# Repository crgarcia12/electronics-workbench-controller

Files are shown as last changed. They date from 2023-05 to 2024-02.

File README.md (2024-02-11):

# My Workbench!
This project builds a shelf for electronic devices that can be controlled remotely or via a control pannel in the shelf

The board has:
- Three shift registers with ULN controllers with 24 high current output
- I2C IO expander with sixteen inputs

## PCB
PCB
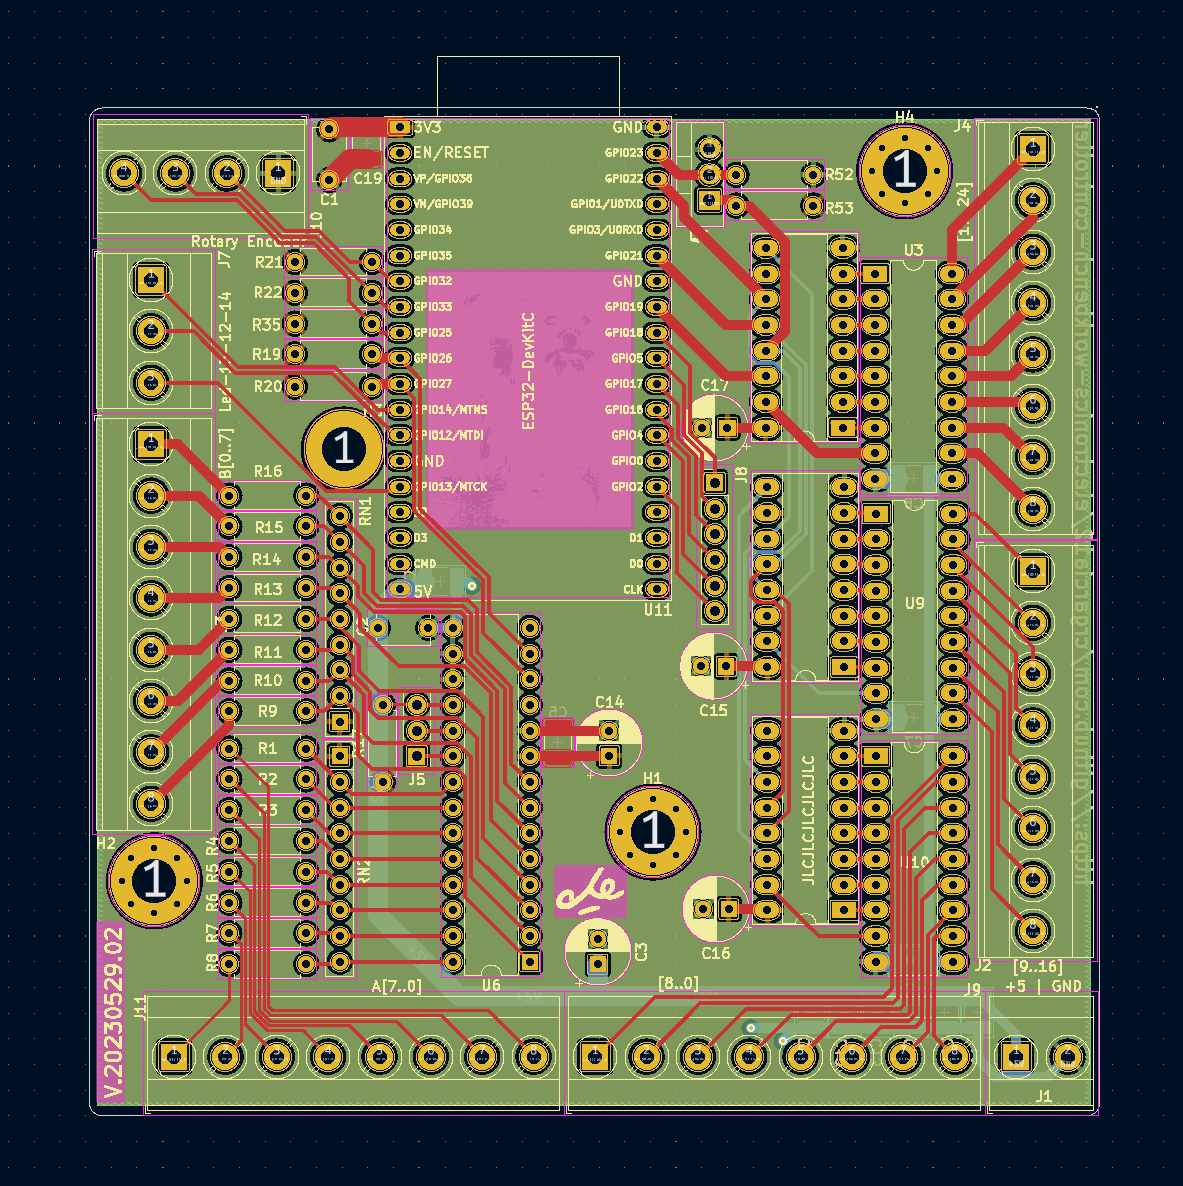
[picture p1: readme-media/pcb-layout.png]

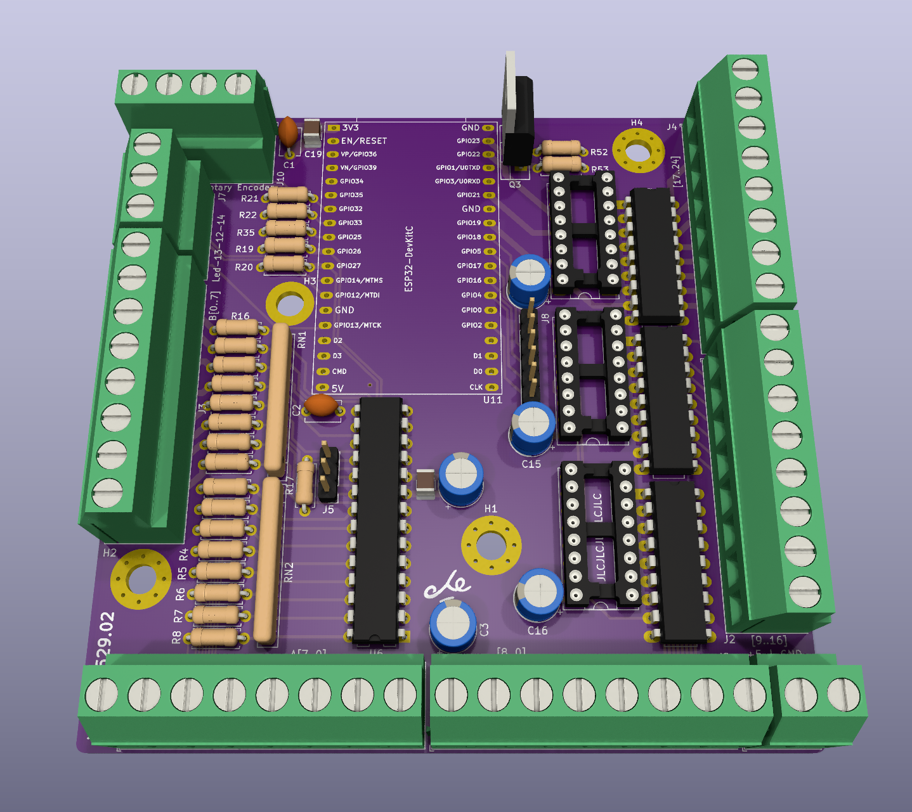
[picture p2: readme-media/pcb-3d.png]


## The Shelf in progress
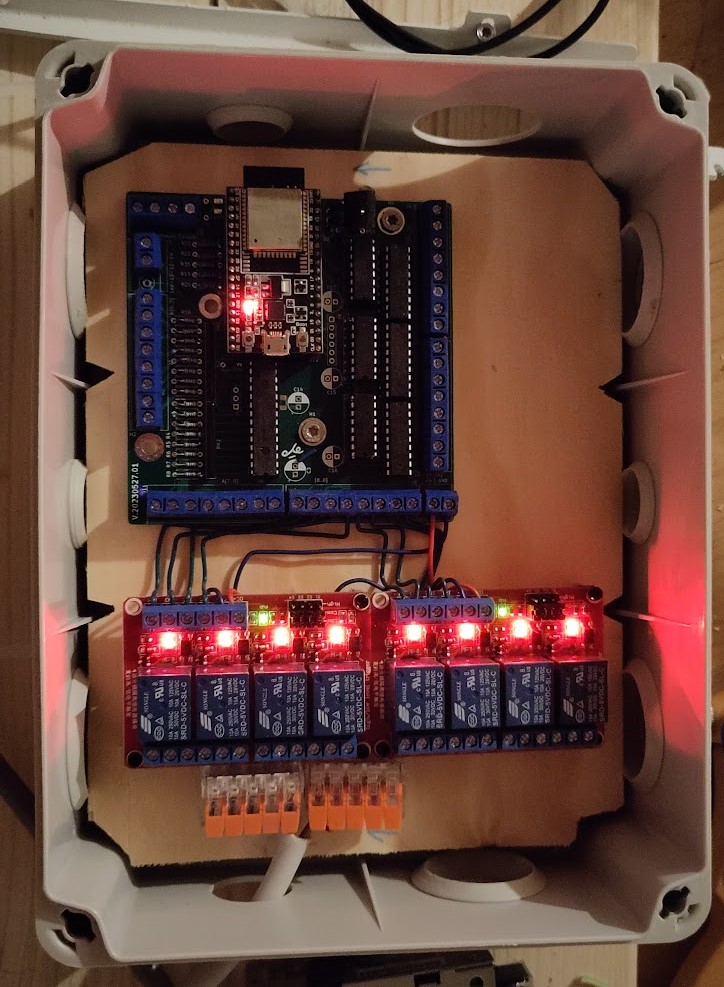
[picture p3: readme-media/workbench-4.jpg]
Workbench

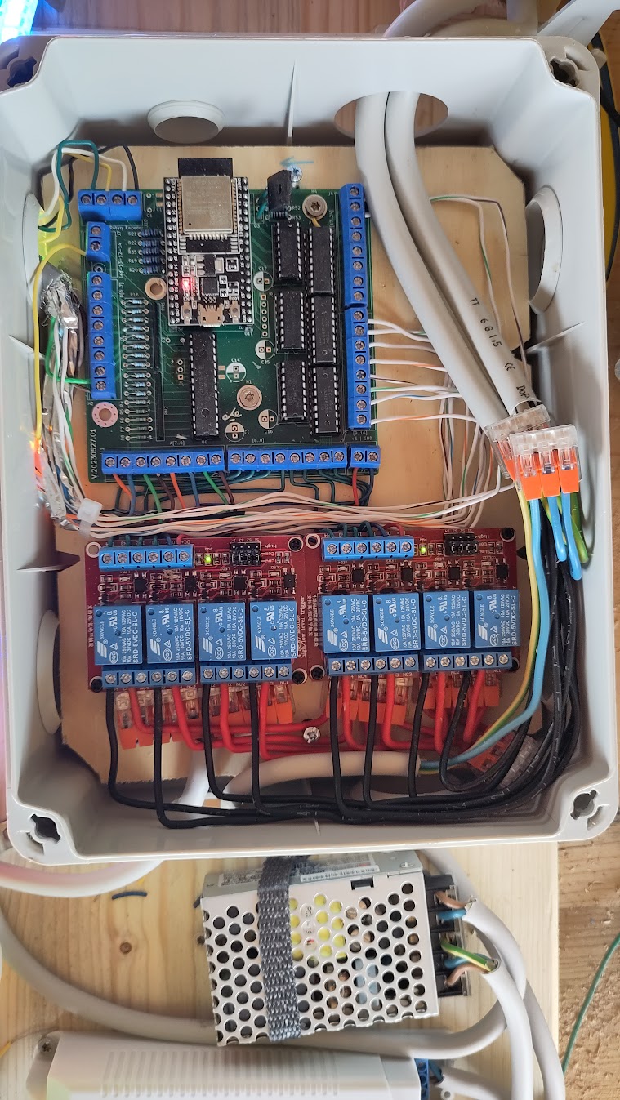
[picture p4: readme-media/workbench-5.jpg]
Workbench

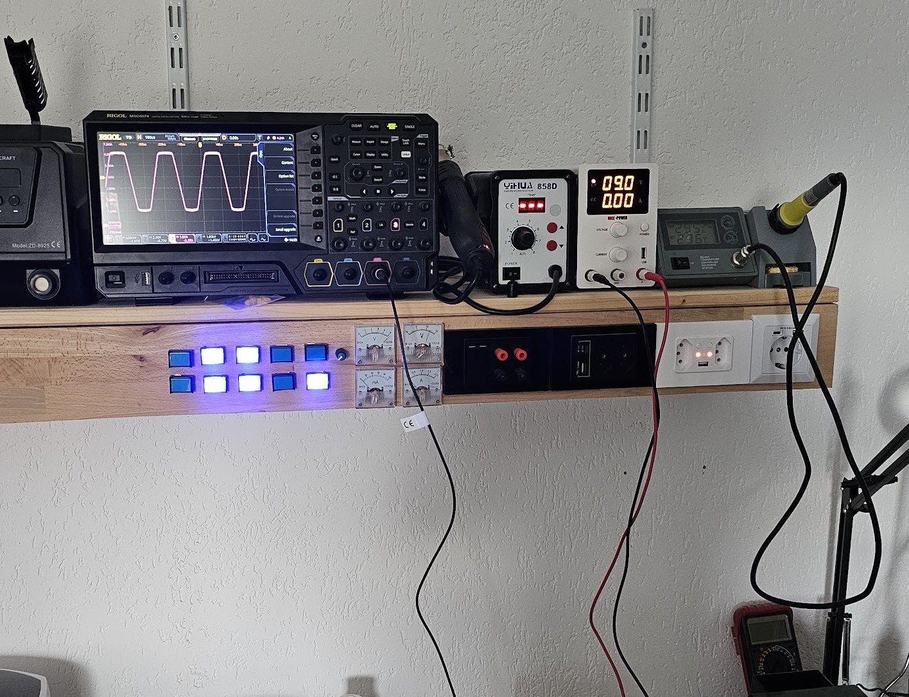
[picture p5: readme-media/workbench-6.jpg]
Workbench

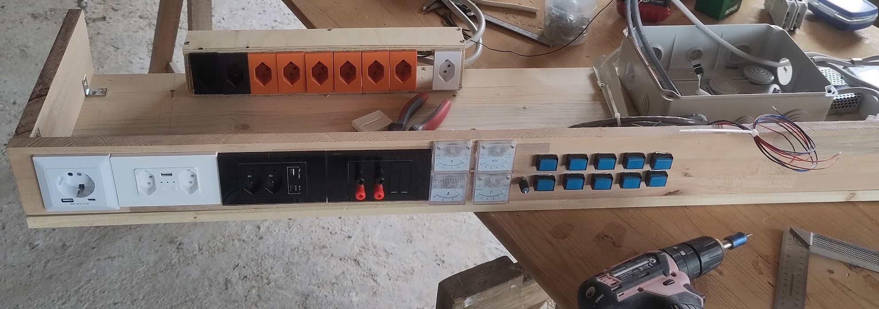
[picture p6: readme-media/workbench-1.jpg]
Workbench

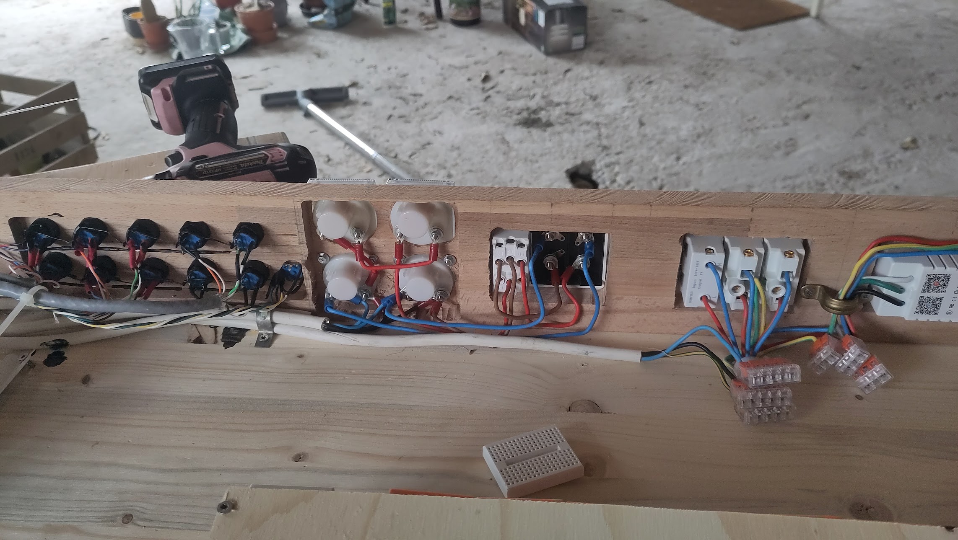
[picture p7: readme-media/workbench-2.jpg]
Workbench

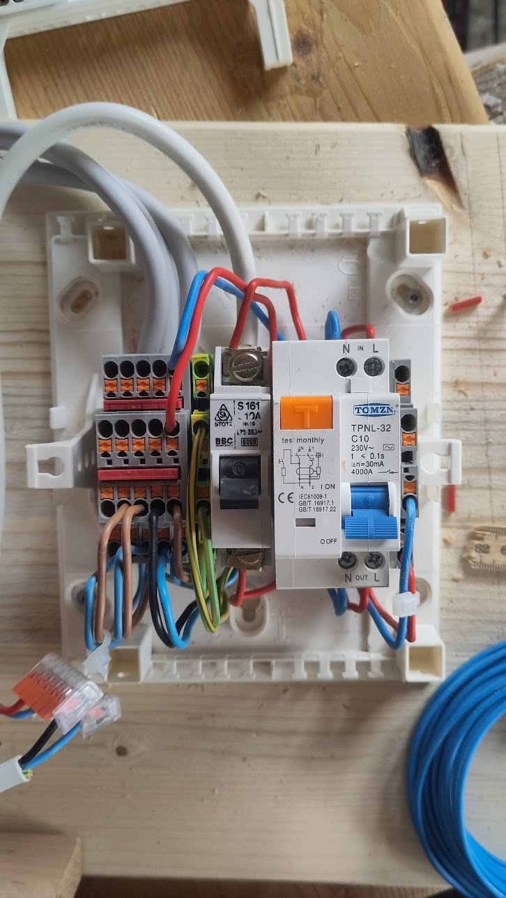
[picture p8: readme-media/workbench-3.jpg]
Workbench

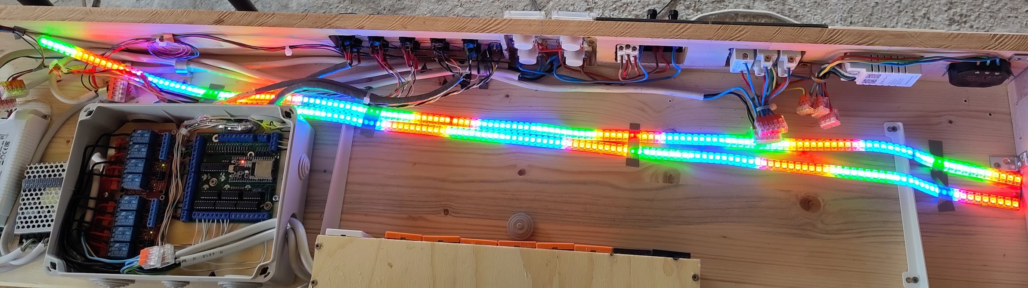
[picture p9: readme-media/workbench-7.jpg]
Workbench


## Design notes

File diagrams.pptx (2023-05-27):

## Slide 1

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
Shalter

TB

TB

TB

5V PS

12V PS

Relay Board 2

Esp32 Board

Relay Board 1

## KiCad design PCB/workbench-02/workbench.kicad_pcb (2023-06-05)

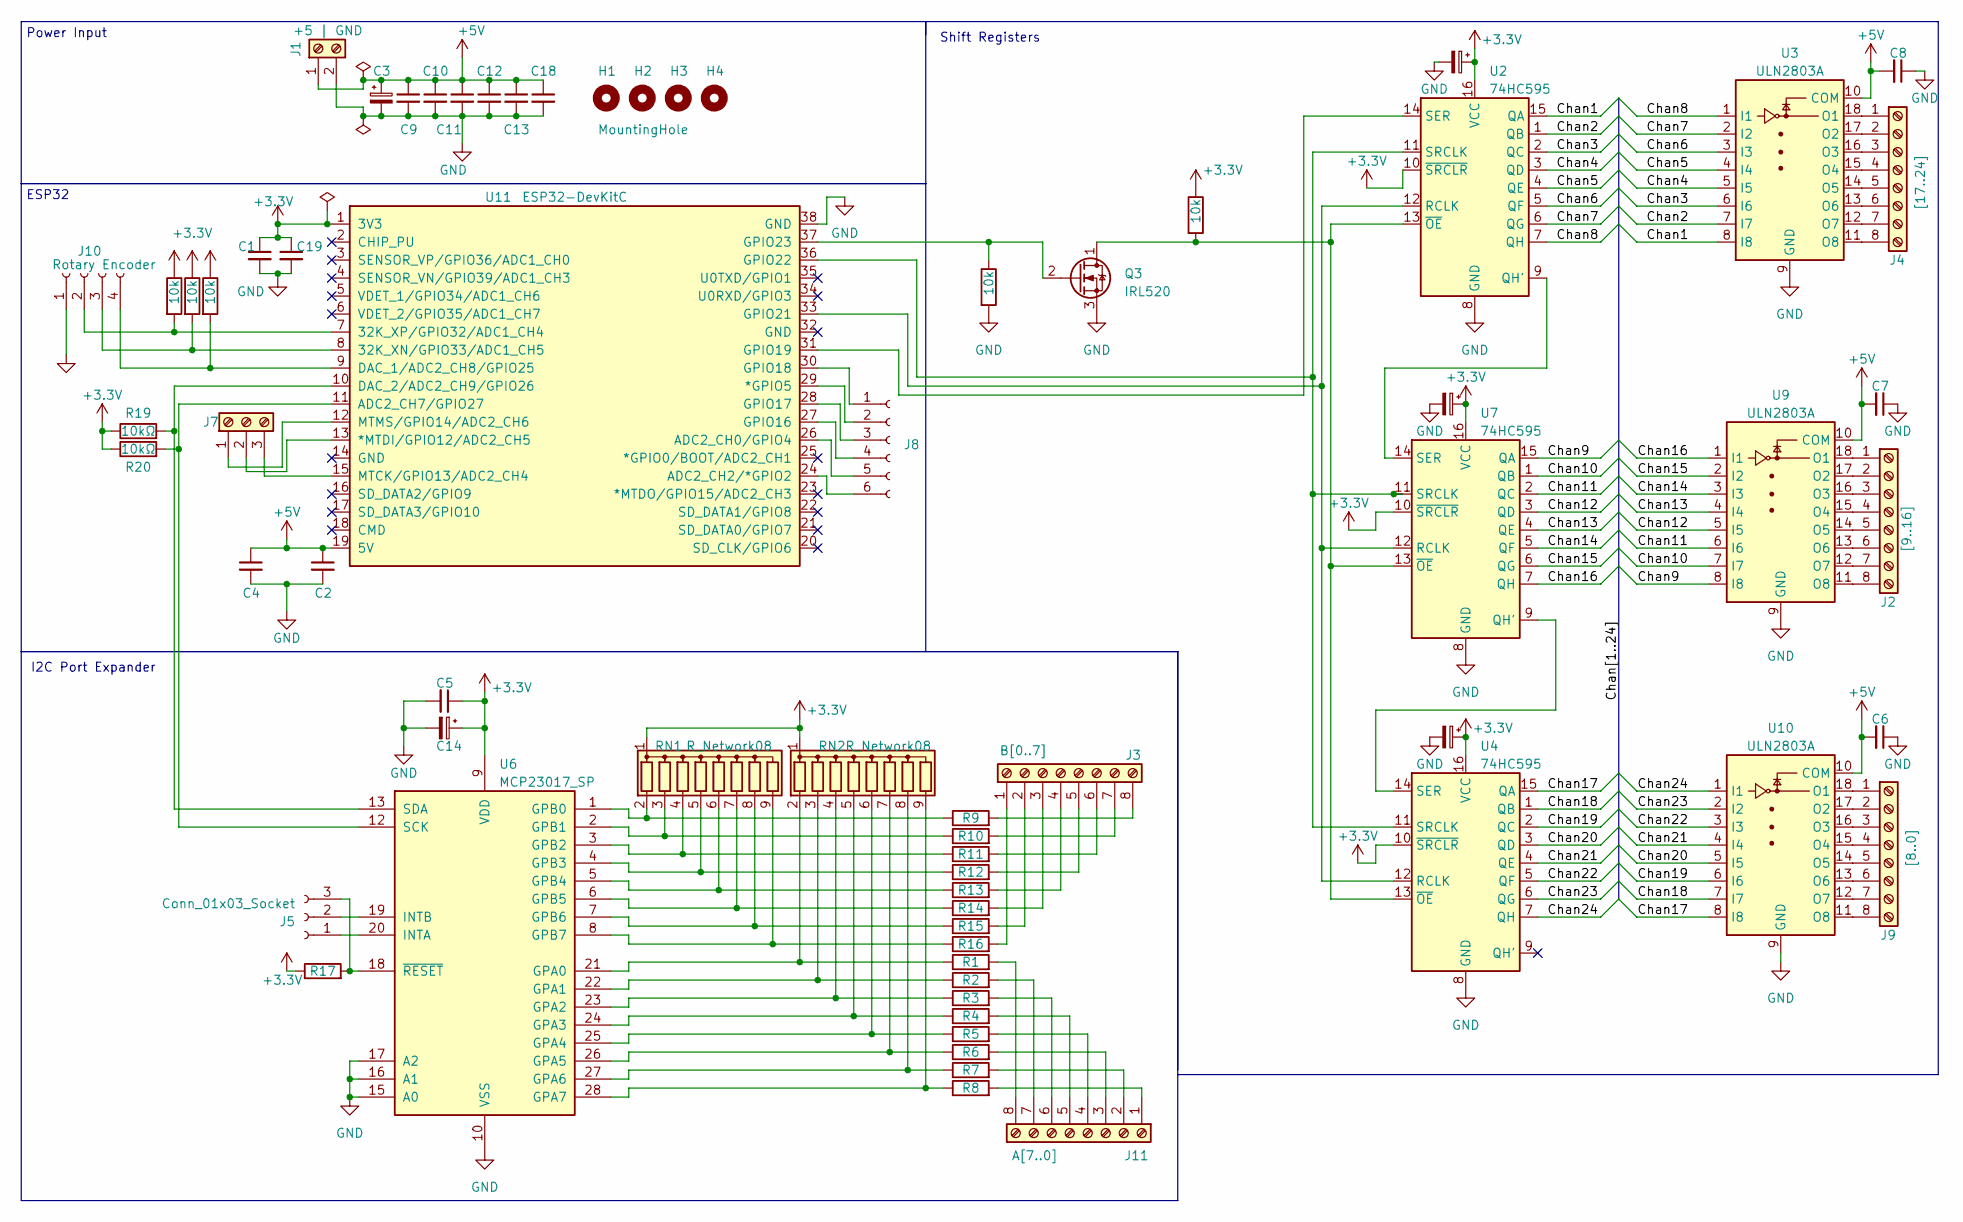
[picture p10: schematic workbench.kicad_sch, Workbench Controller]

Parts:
C1, C2: C; C_Disc_D5.1mm_W3.2mm_P5.00mm
C3, C14, C15, C16, C17: 10uF; CP_Radial_D6.3mm_P2.50mm
C4, C5, C6, C7, C8, C9, C10, C11, C12, C13, C18, C19: C; C_1210_3225Metric_Pad1.33x2.70mm_HandSolder
H1, H2, H4: MountingHole; MountingHole_4.3mm_M4_Pad_Via
H3: MountingHole; MountingHole_4.3mm_M4_DIN965_Pad
J1: +5 | GND; TerminalBlock_Phoenix_MKDS-3-2-5.08_1x02_P5.08mm_Horizontal
J2: [9..16]; TerminalBlock_Phoenix_MKDS-3-8-5.08_1x08_P5.08mm_Horizontal
J3: B[0..7]; TerminalBlock_Phoenix_MKDS-3-8-5.08_1x08_P5.08mm_Horizontal
J4: [17..24]; TerminalBlock_Phoenix_MKDS-3-8-5.08_1x08_P5.08mm_Horizontal
J5: Conn_01x03_Socket; PinHeader_1x03_P2.54mm_Vertical
J7: Led-13-12-14; TerminalBlock_Phoenix_MKDS-3-3-5.08_1x03_P5.08mm_Horizontal
J8: Conn_01x06_Socket; PinHeader_1x06_P2.54mm_Vertical
J9: [8..0]; TerminalBlock_Phoenix_MKDS-3-8-5.08_1x08_P5.08mm_Horizontal
J10: Rotary Encoder; TerminalBlock_Phoenix_MKDS-3-4-5.08_1x04_P5.08mm_Horizontal
J11: A[7..0]; TerminalBlock_Phoenix_MKDS-3-8-5.08_1x08_P5.08mm_Horizontal
Q3: IRL520; TO-220-3_Vertical
R1, R2, R3, R4, R5, R6, R7, R8, R9, R10, R11, R12, R13, R14, R15, R16, R17: R; R_Axial_DIN0207_L6.3mm_D2.5mm_P7.62mm_Horizontal
R19, R20: 10kΩ; R_Axial_DIN0207_L6.3mm_D2.5mm_P7.62mm_Horizontal; JLCPCB C25804
R21, R22, R35, R52, R53: 10k; R_Axial_DIN0207_L6.3mm_D2.5mm_P7.62mm_Horizontal
RN1, RN2: R_Network08; R_Array_SIP9
U2, U4, U7: 74HC595; DIP-16_W7.62mm_Socket_LongPads
U3, U9, U10: ULN2803A; DIP-18_W7.62mm_LongPads
U6: MCP23017_SP; DIP-28_W7.62mm
U11: ESP32-DevKitC

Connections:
+3.3V: C1.1, C5.1, C14.1, C15.1, C16.1, C17.1, C19.1, R17.1, R19.1, R20.1, R21.1, R22.1, R35.1, R53.1, RN1.1 (common), RN2.1 (common), U2.10 (~SRCLR), U2.16 (VCC), U4.10 (~SRCLR), U4.16 (VCC), U6.9 (VDD), U7.10 (~SRCLR), U7.16 (VCC), U11.1 (3V3)
+5V: C2.1, C3.1, C4.1, C6.2, C7.2, C8.2, C9.1, C10.1, C11.1, C12.1, C13.1, C18.1, J1.1, U3.10 (COM), U9.10 (COM), U10.10 (COM), U11.19 (5V)
/Chan1: U2.15 (QA), U3.8 (I8)
/Chan2: U2.1 (QB), U3.7 (I7)
/Chan3: U2.2 (QC), U3.6 (I6)
/Chan4: U2.3 (QD), U3.5 (I5)
/Chan5: U2.4 (QE), U3.4 (I4)
/Chan6: U2.5 (QF), U3.3 (I3)
/Chan7: U2.6 (QG), U3.2 (I2)
/Chan8: U2.7 (QH), U3.1 (I1)
/Chan9: U7.15 (QA), U9.8 (I8)
/Chan10: U7.1 (QB), U9.7 (I7)
/Chan11: U7.2 (QC), U9.6 (I6)
/Chan12: U7.3 (QD), U9.5 (I5)
/Chan13: U7.4 (QE), U9.4 (I4)
/Chan14: U7.5 (QF), U9.3 (I3)
/Chan15: U7.6 (QG), U9.2 (I2)
/Chan16: U7.7 (QH), U9.1 (I1)
/Chan17: U4.15 (QA), U10.8 (I8)
/Chan18: U4.1 (QB), U10.7 (I7)
/Chan19: U4.2 (QC), U10.6 (I6)
/Chan20: U4.3 (QD), U10.5 (I5)
/Chan21: U4.4 (QE), U10.4 (I4)
/Chan22: U4.5 (QF), U10.3 (I3)
/Chan23: U4.6 (QG), U10.2 (I2)
/Chan24: U4.7 (QH), U10.1 (I1)
GND: C1.2, C2.2, C3.2, C4.2, C5.2, C6.1, C7.1, C8.1, C9.2, C10.2, C11.2, C12.2, C13.2, C14.2, C15.2, C16.2, C17.2, C18.2, C19.2, J1.2, J10.1, Q3.3 (S), R52.2, U2.8 (GND), U3.9 (GND), U4.8 (GND), U6.10 (VSS), U6.15 (A0), U6.16 (A1), U6.17 (A2), U7.8 (GND), U9.9 (GND), U10.9 (GND), U11.38 (GND)
unnamed: J2.1, U9.18 (O1)
unnamed: J2.2, U9.17 (O2)
unnamed: J2.3, U9.16 (O3)
unnamed: J2.4, U9.15 (O4)
unnamed: J2.5, U9.14 (O5)
unnamed: J2.6, U9.13 (O6)
unnamed: J2.7, U9.12 (O7)
unnamed: J2.8, U9.11 (O8)
unnamed: J3.1, R16.2
unnamed: J3.2, R15.2
unnamed: J3.3, R14.2
unnamed: J3.4, R13.2
unnamed: J3.5, R12.2
unnamed: J3.6, R11.2
unnamed: J3.7, R10.2
unnamed: J3.8, R9.2
unnamed: J4.1, U3.18 (O1)
unnamed: J4.2, U3.17 (O2)
unnamed: J4.3, U3.16 (O3)
unnamed: J4.4, U3.15 (O4)
unnamed: J4.5, U3.14 (O5)
unnamed: J4.6, U3.13 (O6)
unnamed: J4.7, U3.12 (O7)
unnamed: J4.8, U3.11 (O8)
unnamed: J5.1, U6.20 (INTA)
unnamed: J5.2, U6.19 (INTB)
unnamed: J5.3, R17.2, U6.18 (~RESET)
unnamed: J7.1, U11.12 (MTMS/GPIO14/ADC2_CH6)
unnamed: J7.2, U11.13 (*MTDI/GPIO12/ADC2_CH5)
unnamed: J7.3, U11.15 (MTCK/GPIO13/ADC2_CH4)
unnamed: J8.1, U11.30 (GPIO18)
unnamed: J8.2, U11.29 (*GPIO5)
unnamed: J8.3, U11.28 (GPIO17)
unnamed: J8.4, U11.27 (GPIO16)
unnamed: J8.5, U11.26 (ADC2_CH0/GPIO4)
unnamed: J8.6, U11.24 (ADC2_CH2/*GPIO2)
unnamed: J9.1, U10.18 (O1)
unnamed: J9.2, U10.17 (O2)
unnamed: J9.3, U10.16 (O3)
unnamed: J9.4, U10.15 (O4)
unnamed: J9.5, U10.14 (O5)
unnamed: J9.6, U10.13 (O6)
unnamed: J9.7, U10.12 (O7)
unnamed: J9.8, U10.11 (O8)
unnamed: J10.2, R21.2, U11.7 (32K_XP/GPIO32/ADC1_CH4)
unnamed: J10.3, R22.2, U11.8 (32K_XN/GPIO33/ADC1_CH5)
unnamed: J10.4, R35.2, U11.9 (DAC_1/ADC2_CH8/GPIO25)
unnamed: J11.1, R8.2
unnamed: J11.2, R7.2
unnamed: J11.3, R6.2
unnamed: J11.4, R5.2
unnamed: J11.5, R4.2
unnamed: J11.6, R3.2
unnamed: J11.7, R2.2
unnamed: J11.8, R1.2
unnamed: Q3.1 (D), R53.2, U2.13 (~OE), U4.13 (~OE), U7.13 (~OE)
unnamed: Q3.2 (G), R52.1, U11.37 (GPIO23)
unnamed: R9.1, RN1.2 (R1), U6.1 (GPB0)
unnamed: R10.1, RN1.3 (R2), U6.2 (GPB1)
unnamed: R11.1, RN1.4 (R3), U6.3 (GPB2)
unnamed: R12.1, RN1.5 (R4), U6.4 (GPB3)
unnamed: R13.1, RN1.6 (R5), U6.5 (GPB4)
unnamed: R14.1, RN1.7 (R6), U6.6 (GPB5)
unnamed: R15.1, RN1.8 (R7), U6.7 (GPB6)
unnamed: R16.1, RN1.9 (R8), U6.8 (GPB7)
unnamed: R1.1, RN2.2 (R1), U6.21 (GPA0)
unnamed: R2.1, RN2.3 (R2), U6.22 (GPA1)
unnamed: R3.1, RN2.4 (R3), U6.23 (GPA2)
unnamed: R4.1, RN2.5 (R4), U6.24 (GPA3)
unnamed: R5.1, RN2.6 (R5), U6.25 (GPA4)
unnamed: R6.1, RN2.7 (R6), U6.26 (GPA5)
unnamed: R7.1, RN2.8 (R7), U6.27 (GPA6)
unnamed: R8.1, RN2.9 (R8), U6.28 (GPA7)
unnamed: U2.9 (QH'), U7.14 (SER)
unnamed: U4.14 (SER), U7.9 (QH')
unnamed: R20.2, U6.12 (SCK), U11.11 (ADC2_CH7/GPIO27)
unnamed: R19.2, U6.13 (SDA), U11.10 (DAC_2/ADC2_CH9/GPIO26)
unnamed: U2.14 (SER), U11.31 (GPIO19)
unnamed: U2.12 (RCLK), U4.12 (RCLK), U7.12 (RCLK), U11.33 (GPIO21)
unnamed: U2.11 (SRCLK), U4.11 (SRCLK), U7.11 (SRCLK), U11.36 (GPIO22)

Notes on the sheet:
ESP32
Power Input
Shift Registers
I2C Port Expander

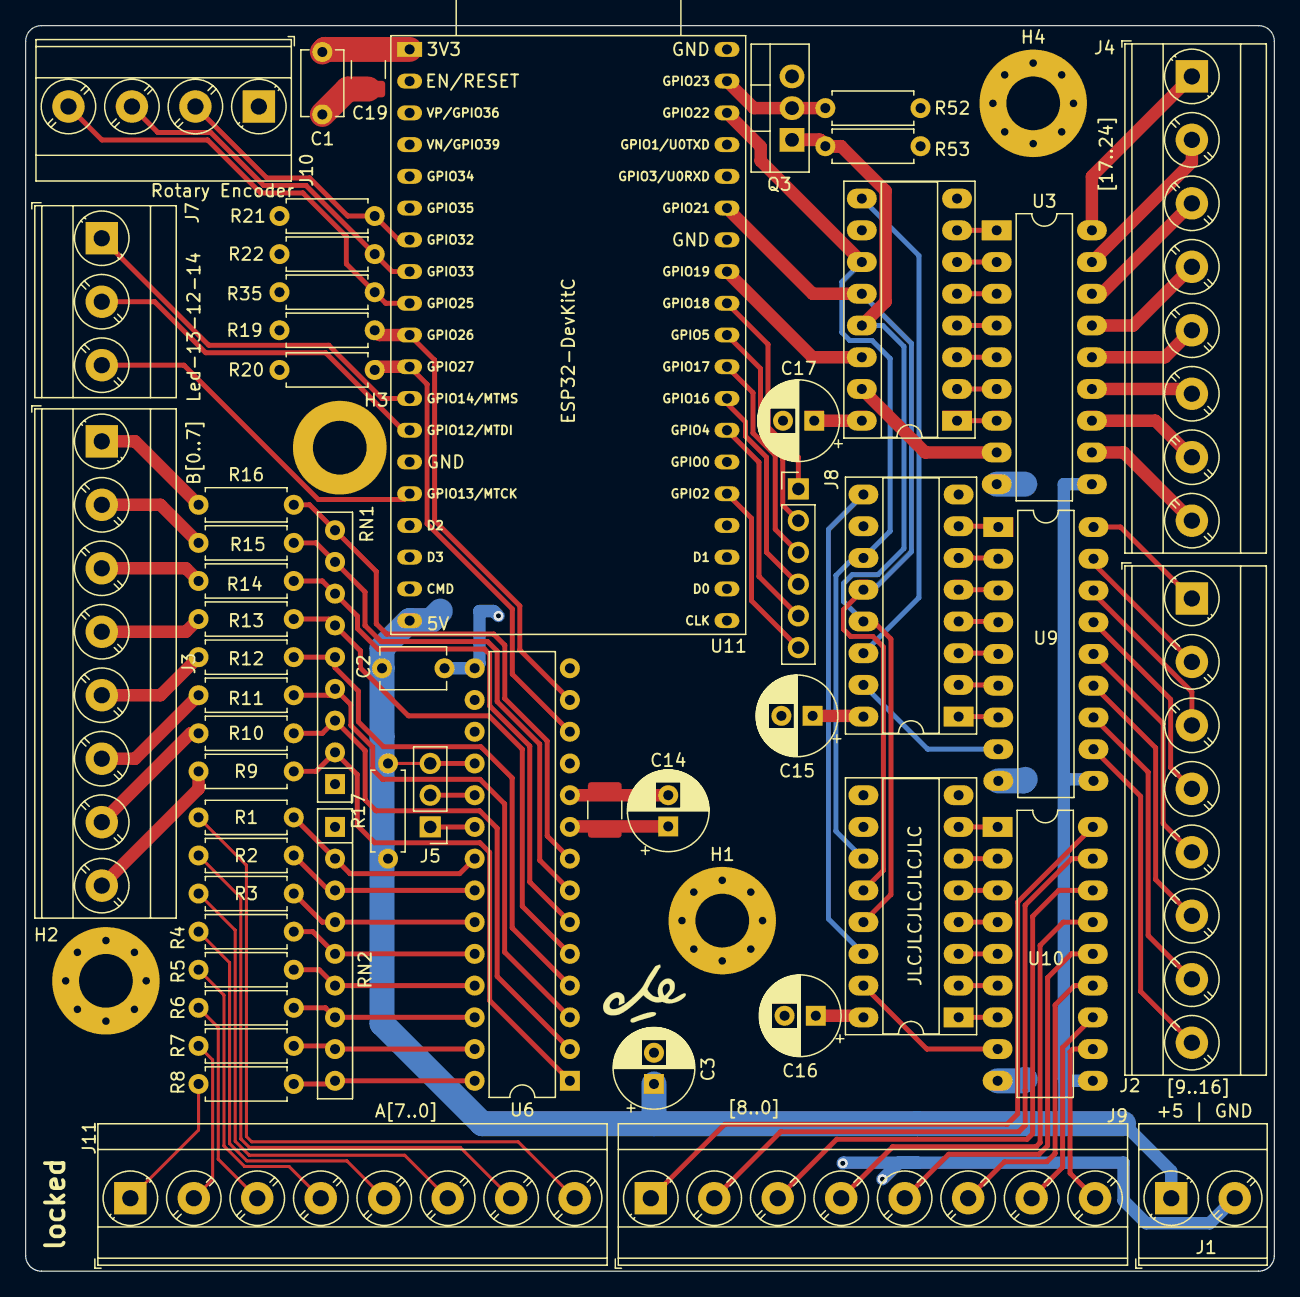
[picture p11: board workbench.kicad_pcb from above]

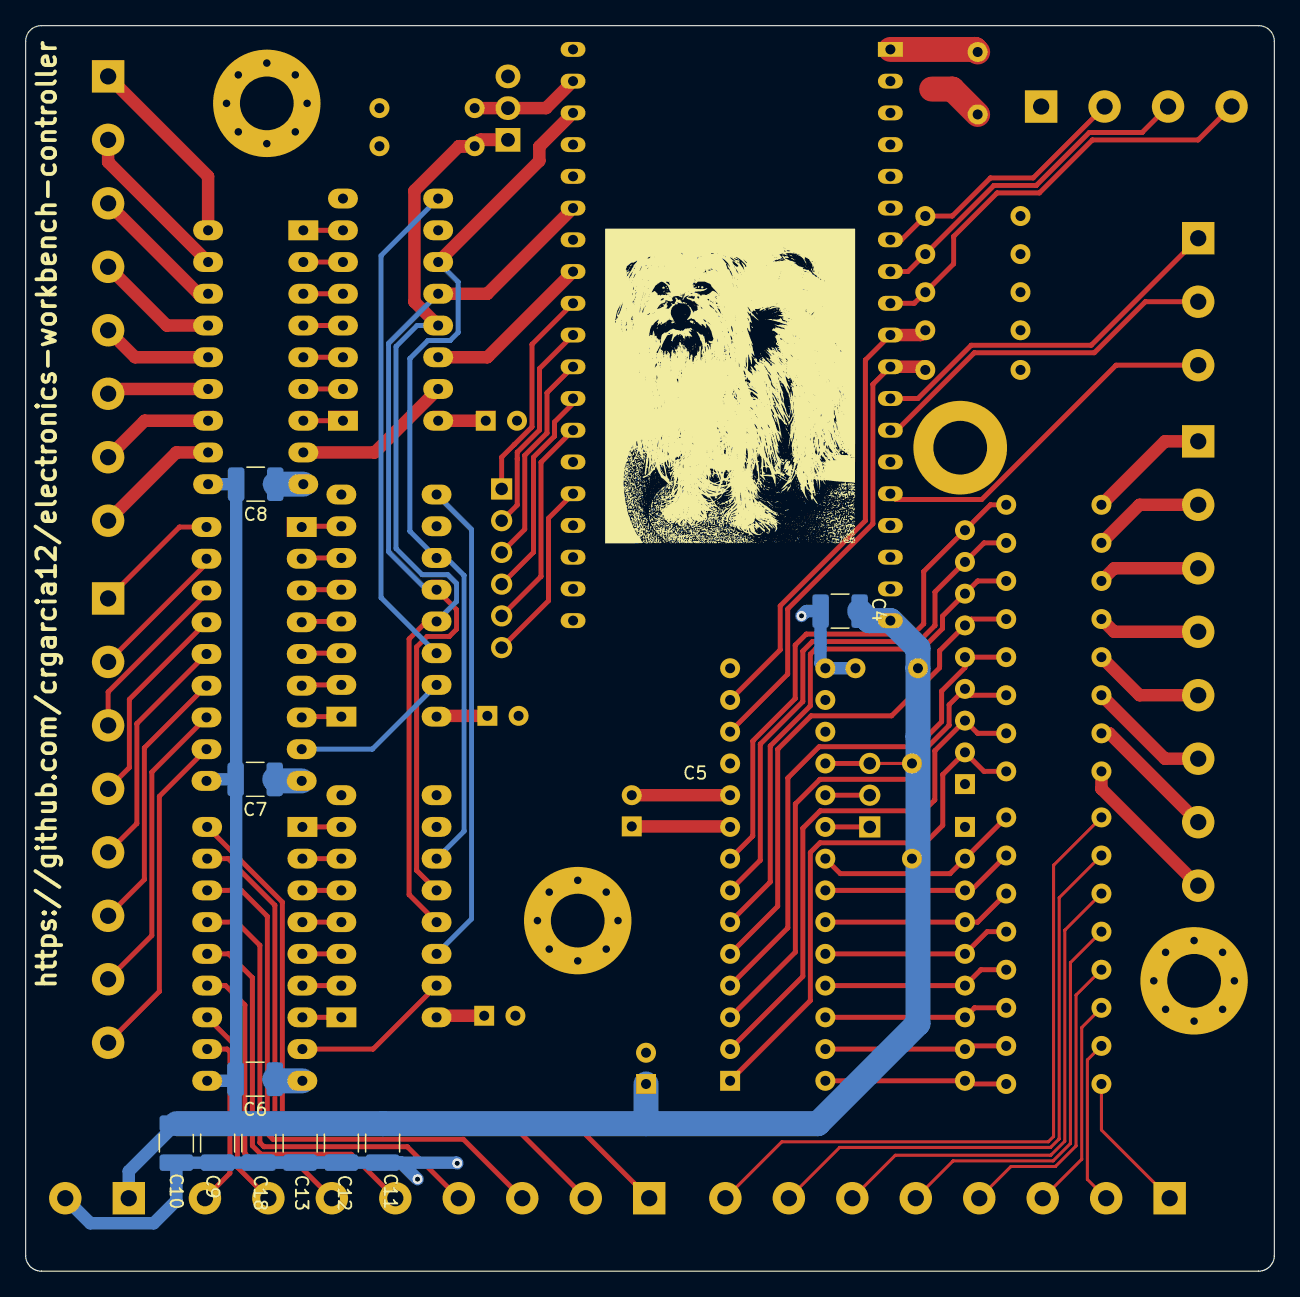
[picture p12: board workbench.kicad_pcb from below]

Board: 4 copper layers, 99.9 x 99.7 mm, 68 parts (10 on the bottom side), 107 nets.

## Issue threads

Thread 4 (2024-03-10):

Expanding it to 32 relays

spplecxer, 2024-03-10:
Hi. Coming here from your other project :-) I guess this is easy to expand to more relays, right?
What about triggering the relays from another like a 12v wall switch? I know your other project does that but like I said in my post there my goal is to have separate parts and be able to replace any component right away. I need to be able to switch on the light from both the app and the switch and why not a motion sensor 😬

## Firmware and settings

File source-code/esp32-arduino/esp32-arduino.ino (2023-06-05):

#include <Wire.h>
#include <Adafruit_MCP23X17.h>
#include "AiEsp32RotaryEncoder.h"
#include <FastLED.h>

Adafruit_MCP23X17 mcp;

#define NR_INPUTS  16
#define NR_OUTPUTS 24  

#define NR_RELAYS  8
#define NR_BUTTONS 10

// The component is called 74HC595. 
// But variables cannot start with a number :)
#define U74HC_SI       19
#define U74HC_RCK      21
#define U74HC_SCK      22
#define OutputEnabled  23

// I2C for the MCP23017
#define SDA            26
#define SCL            27

// Rotary encoder
#define ROTARY_ENCODER_A_PIN 25
#define ROTARY_ENCODER_B_PIN 33
#define ROTARY_ENCODER_BUTTON_PIN 32
#define ROTARY_ENCODER_VCC_PIN -1
#define ROTARY_ENCODER_STEPS 4
AiEsp32RotaryEncoder rotaryEncoder = AiEsp32RotaryEncoder(ROTARY_ENCODER_A_PIN, ROTARY_ENCODER_B_PIN, ROTARY_ENCODER_BUTTON_PIN, ROTARY_ENCODER_VCC_PIN, ROTARY_ENCODER_STEPS);

void IRAM_ATTR readEncoderISR()
{
    rotaryEncoder.readEncoder_ISR();
}

// LED
#define NUM_LEDS  800
#define LED_DATA_PIN 12

// GLobal State
bool OutputStatus[NR_OUTPUTS];
bool PreviousButtonStatus[NR_BUTTONS];
CRGB Leds[NUM_LEDS];
bool LedsAreOn;
int LedsAreStarting;
int gHue;

void setup()
{
  Serial.begin(115200);
  Serial.println("V9 - Initializing");

  pinMode(OutputEnabled, OUTPUT);
  digitalWrite(OutputEnabled, LOW);

  FastLED.addLeds<WS2812, LED_DATA_PIN, RGB>(Leds, NUM_LEDS);

  // Shift register
  pinMode(U74HC_SCK, OUTPUT);
  pinMode(U74HC_RCK, OUTPUT);
  pinMode(U74HC_SI, OUTPUT);

  digitalWrite(U74HC_SCK, LOW);
  digitalWrite(U74HC_RCK, LOW);
  digitalWrite(U74HC_SI, LOW);

  // I2C expander
  Wire.setClock(20000);
  Wire.begin(SDA, SCL); // wake up I2C bus
  try {
    if (!mcp.begin_I2C()) {
      Serial.println("Error. I2C not initialized");
      //while (1);
    }
  }catch (String error){
    Serial.println(error);
  }

  for (int i = 0; i < NR_INPUTS; i++ ) {
    mcp.pinMode(i, INPUT);
  }

  // Before activating the relays, let's give some time to the input pins to estabilize
  Serial.println("Delaying relays activation");

  delay(3000);
  digitalWrite(OutputEnabled, HIGH);

  Serial.println("Relays activated!");

  // Rotary encoder
  pinMode(ROTARY_ENCODER_A_PIN, INPUT_PULLUP);
  pinMode(ROTARY_ENCODER_B_PIN, INPUT_PULLUP);
  rotaryEncoder.begin();
  rotaryEncoder.setup(readEncoderISR);
  //set boundaries and if values should cycle or not. 
  bool circleValues = false;
  int minValue = 0;
  int maxValue = 100;
  rotaryEncoder.setBoundaries(0, 25, circleValues);
  rotaryEncoder.setAcceleration(0); // aceleration helps reach higher values faster by increasing the increment if you move the encoder a lot
  
  EVERY_N_MILLISECONDS( 20 ) { gHue++; } 
}

void serialPrintRelayChange(int relayIndex)
{
      Serial.print("Switching relay '");
      Serial.print(relayIndex);
      Serial.print("'. new state: ");
      Serial.print(OutputStatus[relayIndex]);
      Serial.print(" Outputs: ");
      for(int i = 0; i < NR_OUTPUTS; i++)
      {
        Serial.print(OutputStatus[i]);
      }
      Serial.println(".");
}

void ProcessButtons()
{
  // I2C
  // First buttons are for relay
  for(int i = 0; i < NR_BUTTONS; i++)
  {
    int buttonValue = !mcp.digitalRead(i);

    // This logic makes sure we change the state of the relay only once if the button is holded for some milliseconds (debouncing)
    if(!buttonValue)
    {
      PreviousButtonStatus[i] = false;
    }
    else if(!PreviousButtonStatus[i])
    {
      // Button is now HIGH and previously was LOW, so change the relay state
      if( i < NR_RELAYS)
      {
        // The button has a relay associated
        OutputStatus[i] = !OutputStatus[i];
      }
      OutputStatus[i + NR_RELAYS] = !OutputStatus[i + NR_RELAYS]; // Button light
      PreviousButtonStatus[i] = true;

      serialPrintRelayChange(i);
    }
  }
}

struct RotaryEncoderState
{
  bool changed;
  int value;
  bool clicked;
};

struct RotaryEncoderState ProcessRotaryEncoder()
{
  RotaryEncoderState encoderState = {rotaryEncoder.encoderChanged(), rotaryEncoder.readEncoder(), rotaryEncoder.isEncoderButtonClicked() };
  
  if (encoderState.changed)
  {
    Serial.print("Value: ");
    Serial.println(encoderState.value);
  }
  if (encoderState.clicked)
  {
    Serial.println("Encoder cliecked!");
  }  
  
  return encoderState;
}

void ProcessLeds(RotaryEncoderState encoderState)
{
  if(encoderState.clicked)
  {
    if(!LedsAreOn)
    {
      LedsAreOn = true;
      LedsAreStarting = 1;
      Serial.print("Turning on leds. Value: ");
      Serial.println(encoderState.value);
    }
    else
    {
      LedsAreOn = false;
      LedsAreStarting = 0;
      for(int j = 0; j < NUM_LEDS; j++)
      {
        Leds[j] = CRGB(0, 0, 0);
      }
    }
  }

  if(LedsAreStarting > 900)
  {
    // a colored dot sweeping back and forth, with fading trails
    // fadeToBlackBy( Leds, NUM_LEDS, 20);
    // int pos = beatsin16( 13, 0, NUM_LEDS-1 );
    // Leds[pos] += CHSV( gHue, 255, 192);
    for(int j = 0; j < NUM_LEDS; j++)
    {
      Leds[j] = CRGB(0, 0, encoderState.value * 10);
    }
  }
  else if(LedsAreOn)
  {
    // Leds
    for(int j = 0; j < NUM_LEDS / 10; j++)
    {
      for(int i = 0; i < 10; i++)
      {
        if(j % 3 == 0)
        {
          Leds[i+j*10] = CRGB(encoderState.value * 10, 0, 0);
        }
        if(j % 3 == 1)
        {
          Leds[i+j*10] = CRGB(0, encoderState.value * 10, 0);
        }
        if(j % 3 == 2)
        {
          Leds[i+j*10] = CRGB(0, 0, encoderState.value * 10);
        }
      }
    }
  }
  
  FastLED.show();
}

void loop()
{
  ProcessButtons();
  writeOutputStatus();

  RotaryEncoderState encoderState = ProcessRotaryEncoder();
  ProcessLeds(encoderState);

  delay(10);
}

void writeOutputStatus()
{
  // Latching
  digitalWrite(U74HC_RCK, LOW);

  for(int i = 0; i < NR_OUTPUTS; i++)
  {
    digitalWrite(U74HC_SCK, LOW);
    digitalWrite(U74HC_SI, OutputStatus[i]);
    digitalWrite(U74HC_SCK, HIGH);
  }

  // Unlatching
  digitalWrite(U74HC_RCK, HIGH);
}

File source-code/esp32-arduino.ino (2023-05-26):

#include <Wire.h>
#include <Adafruit_MCP23X17.h>
#include "AiEsp32RotaryEncoder.h"

Adafruit_MCP23X17 mcp;

// The component is called 74HC595. 
// But variables cannot start with a number :)
#define U74HC_SI       19
#define U74HC_RCK      21
#define U74HC_SCK      22
#define OutputEnabled  23

// I2C for the MCP23017
#define SDA            32
#define SCL            33

// Rotary encoder
#define ROTARY_ENCODER_A_PIN 16
#define ROTARY_ENCODER_B_PIN 18
#define ROTARY_ENCODER_BUTTON_PIN 17
#define ROTARY_ENCODER_VCC_PIN -1
#define ROTARY_ENCODER_STEPS 4
AiEsp32RotaryEncoder rotaryEncoder = AiEsp32RotaryEncoder(ROTARY_ENCODER_A_PIN, ROTARY_ENCODER_B_PIN, ROTARY_ENCODER_BUTTON_PIN, ROTARY_ENCODER_VCC_PIN, ROTARY_ENCODER_STEPS);

// State
bool RelayStatus[8];
bool PreviousButtonStatus[8];

void IRAM_ATTR readEncoderISR()
{
    rotaryEncoder.readEncoder_ISR();
}

void setup()
{
  Serial.begin(115200);
  serialPrintln("Initializing");

  pinMode(OutputEnabled, OUTPUT);
  digitalWrite(OutputEnabled, LOW);

  // Shift register
  pinMode(U74HC_SCK, OUTPUT);
  pinMode(U74HC_RCK, OUTPUT);
  pinMode(U74HC_SI, OUTPUT);

  digitalWrite(U74HC_SCK, LOW);
  digitalWrite(U74HC_RCK, LOW);
  digitalWrite(U74HC_SI, LOW);

  // I2C expander
  Wire.setClock(20000);
  Wire.begin(SDA, SCL); // wake up I2C bus
  try {
    if (!mcp.begin_I2C()) {
      serialPrintln("Error. I2C not initialized");
      //while (1);
    }
  }catch (String error){
    Serial.println(error);
  }

  for (int i = 0; i < 16; i++ ) {
    mcp.pinMode(i, INPUT);
  }

  // Before activating the relays, let's give some time to the input pins to estabilize
  serialPrintln("Delaying relays activation");

  delay(3000);
  digitalWrite(OutputEnabled, HIGH);

  serialPrintln("Relays activated!");

  // Rotary encoder
  pinMode(ROTARY_ENCODER_A_PIN, INPUT_PULLUP);
  pinMode(ROTARY_ENCODER_B_PIN, INPUT_PULLUP);
  rotaryEncoder.begin();
  rotaryEncoder.setup(readEncoderISR);
  //set boundaries and if values should cycle or not. 
  bool circleValues = false;
  int minValue = 0;
  int maxValue = 100;
  rotaryEncoder.setBoundaries(0, 100, circleValues);
  rotaryEncoder.setAcceleration(0); // aceleration helps reach higher values faster by increasing the increment if you move the encoder a lot
}

void loop()
{
  int buttonValue;

  // I2C
  for(int i = 0; i < 8; i++)
  {
    buttonValue = !mcp.digitalRead(i);

    // This logic makes sure we change the state of the relay only once if the button is holded
    if(!buttonValue)
    {
      PreviousButtonStatus[i] = false;
    }
    else if(!PreviousButtonStatus[i])
    {
      // Button is now HIGH and previously was LOW, so change the relay state
      RelayStatus[i] = !RelayStatus[i];
      PreviousButtonStatus[i] = true;

      if (i == 5 || i == 6)
      {
        serialPrint("Switching relay '");
        Serial.print(i);
        Serial.print("'. new state: ");
        Serial.println(RelayStatus[i]);
      }
    }
    
    // Rotary encoder
    //dont print anything unless value changed
    if (rotaryEncoder.encoderChanged())
    {
      serialPrint("Value: ");
      Serial.println(rotaryEncoder.readEncoder());
    }
    if (rotaryEncoder.isEncoderButtonClicked())
    {
      serialPrintln("Encoder cliecked!");
    }
  }
  writeRelaysStatus();
  delay(10);
}

void writeRelaysStatus()
{
  // Latching
  digitalWrite(U74HC_RCK, LOW);

  // First 8 bits are for the relays, sencond time are for the button LED
  for(int j = 0; j < 2; j++)
  {
    for(int i = 0; i < 8; i++)
    {
      digitalWrite(U74HC_SCK, LOW);
      digitalWrite(U74HC_SI, RelayStatus[i]);
      digitalWrite(U74HC_SCK, HIGH);
    }
  }

  // Unlatching
  digitalWrite(U74HC_RCK, HIGH);
}

void serialPrint(String msg)
{
  Serial.print("v9:");
  Serial.print(msg);
}

void serialPrintln(String msg)
{
  serialPrint(msg);
  Serial.println(".");
}

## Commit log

2023-05-26 initial project
    [workbench-B_Cu.gbr, workbench-B_Mask.gbr, workbench-B_Paste.gbr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]
2023-05-27 adding pins for Leds. Silkscreen. logos. production files
    [workbench-B_Cu.gbr, workbench-B_Mask.gbr, workbench-B_Paste.gbr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]
2023-05-27 V01 to JLC
    [workbench.kicad_pcb, workbench.kicad_sch]
2023-05-29 adding v2, which contains pullup resistor from MCP23017.Reset to e.eV
    [workbench.kicad_pcb, workbench.kicad_sch]
2023-06-05 arduino code
